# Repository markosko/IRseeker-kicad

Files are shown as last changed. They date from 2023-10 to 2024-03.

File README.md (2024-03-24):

View this project on [CADLAB.io](https://cadlab.io/project/27377).

# IRseeker-kicad

Used as replacement for IRseeker sensor and similar for Lightweight / Entry leagues with infra ball in Robocup Junior, based on STM32G431CBU6 and TSSP4038

With communication over I2C or Serial protocol.

Serial over **TX_3V** / **RX_3V** pins is **only 3.3V tolerant**!

Serial over **TX3_5V** / **RX3_5V** pins is **5V tolerant**.

**I2C** is 5V tolerant.

Logic **AND** gates **HEF4082BT** at **U2** and **U4** are optional for chip at PC6 pin input to detect if any TSSP4038 detects ball.

**AMS1117** part is not needed in case of powering from 3.3V source

Programmed by external STLINK or similar over SWD pins at J13 header.

[Basic serial code](https://github.com/markosko/IRseeker-stmduino-serial)

[Basic I2C code](https://github.com/markosko/IRseeker-stmduino-i2c)

# 3D view from KiCad

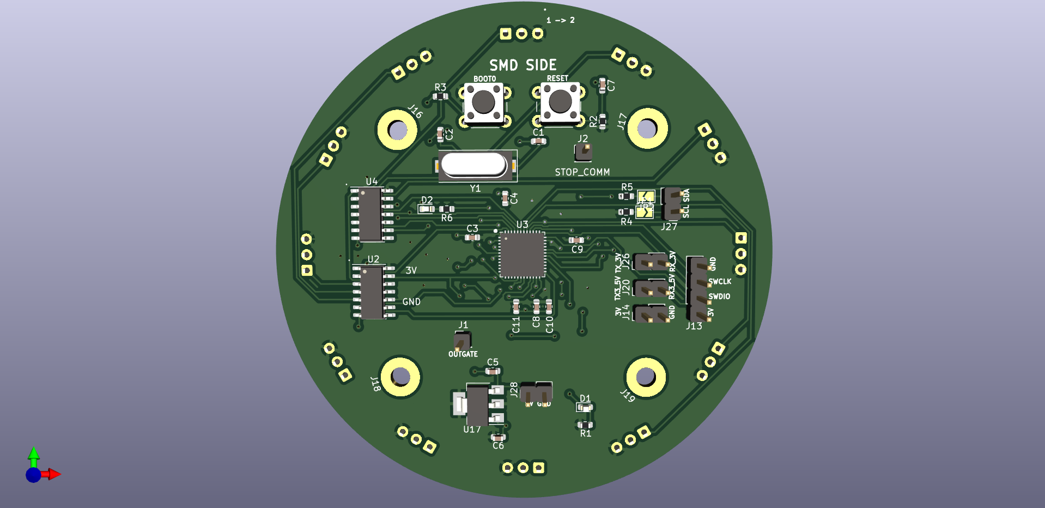
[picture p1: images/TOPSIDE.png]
Top side


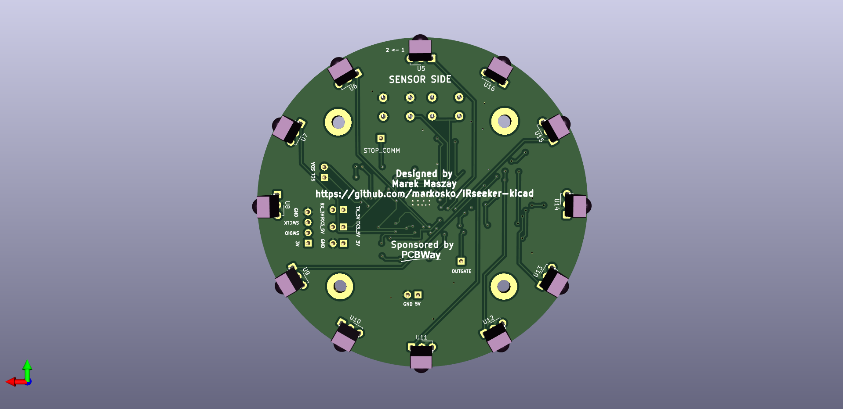
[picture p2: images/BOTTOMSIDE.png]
Bottom side


# Assembled images

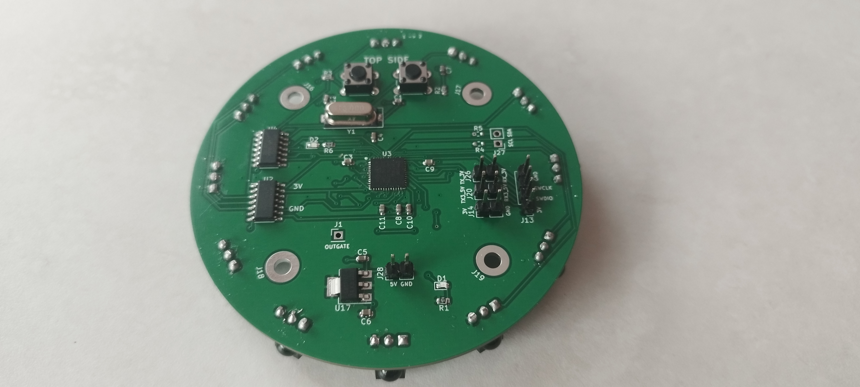
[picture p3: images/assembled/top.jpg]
Top side assembled


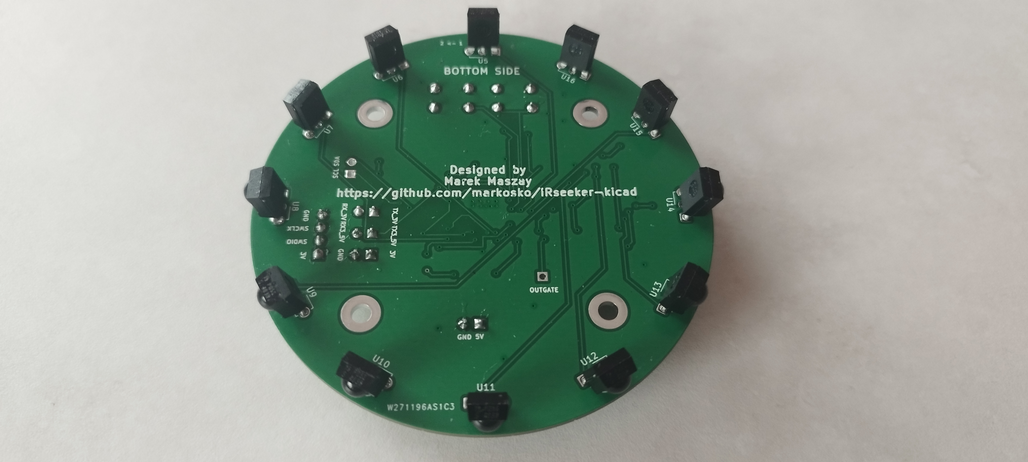
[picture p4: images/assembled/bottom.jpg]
Bottom side assembled


# Sponsored by

<p align="center">
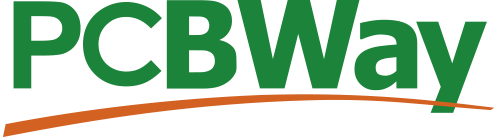
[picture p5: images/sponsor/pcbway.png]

</p>
<p align=center>
A big thanks to <a href="https://www.pcbway.com/">PCBway</a> for sponsoring my project! Their rapid-prototyping services provided top-quality PCB boards, streamlining the entire process from order to delivery. I was particularly impressed by their outstanding customer support, which was willing to change few details.
</p>

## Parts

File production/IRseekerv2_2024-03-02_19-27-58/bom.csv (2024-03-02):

Designator | Footprint | Quantity | Value | LCSC Part #
C1, C2 | 0603 | 2 | 10pF
C10 | 0603 | 1 | 4.7uF
C11, C3, C4, C7, C8, C9 | 0603 | 6 | 100nF
C5, C6 | 0603 | 2 | 10uF
D1, D2 | 0603 | 2 | LED
J1 | PinHeader_1x01_P2.54mm_Vertical | 1 | Conn_01x01_Pin
J13 | PinHeader_1x04_P2.54mm_Vertical | 1 | Conn_01x04_Pin
J14, J20, J26, J27, J28 | PinHeader_1x02_P2.54mm_Vertical | 5 | Conn_01x02_Pin
J16, J17, J18, J19 | MountingHole_3.2mm_M3_Pad | 4 | G
R1, R6 | 0603 | 2 | 330R
R2, R3 | 0603 | 2 | 10kR
R4, R5 | 0603 | 2 | 4.7kR
SW1, SW2 | SW_PUSH_6mm | 2 | SW_Push
U10, U11, U12, U13, U14, U15, U16, U5, U6, U7, U8, U9 | Vishay_MINICAST-3Pin | 12 | TSSP4038
U17 | SOT-223-3_TabPin2 | 1 | AMS1117-3.3
U2, U4 | SO-14_3.9x8.65mm_P1.27mm | 2 | HEF4082BT
U3 | QFN-48-1EP_7x7mm_P0.5mm_EP5.6x5.6mm | 1 | STM32G431CBUx
Y1 | Crystal_SMD_HC49-SD | 1 | Crystal

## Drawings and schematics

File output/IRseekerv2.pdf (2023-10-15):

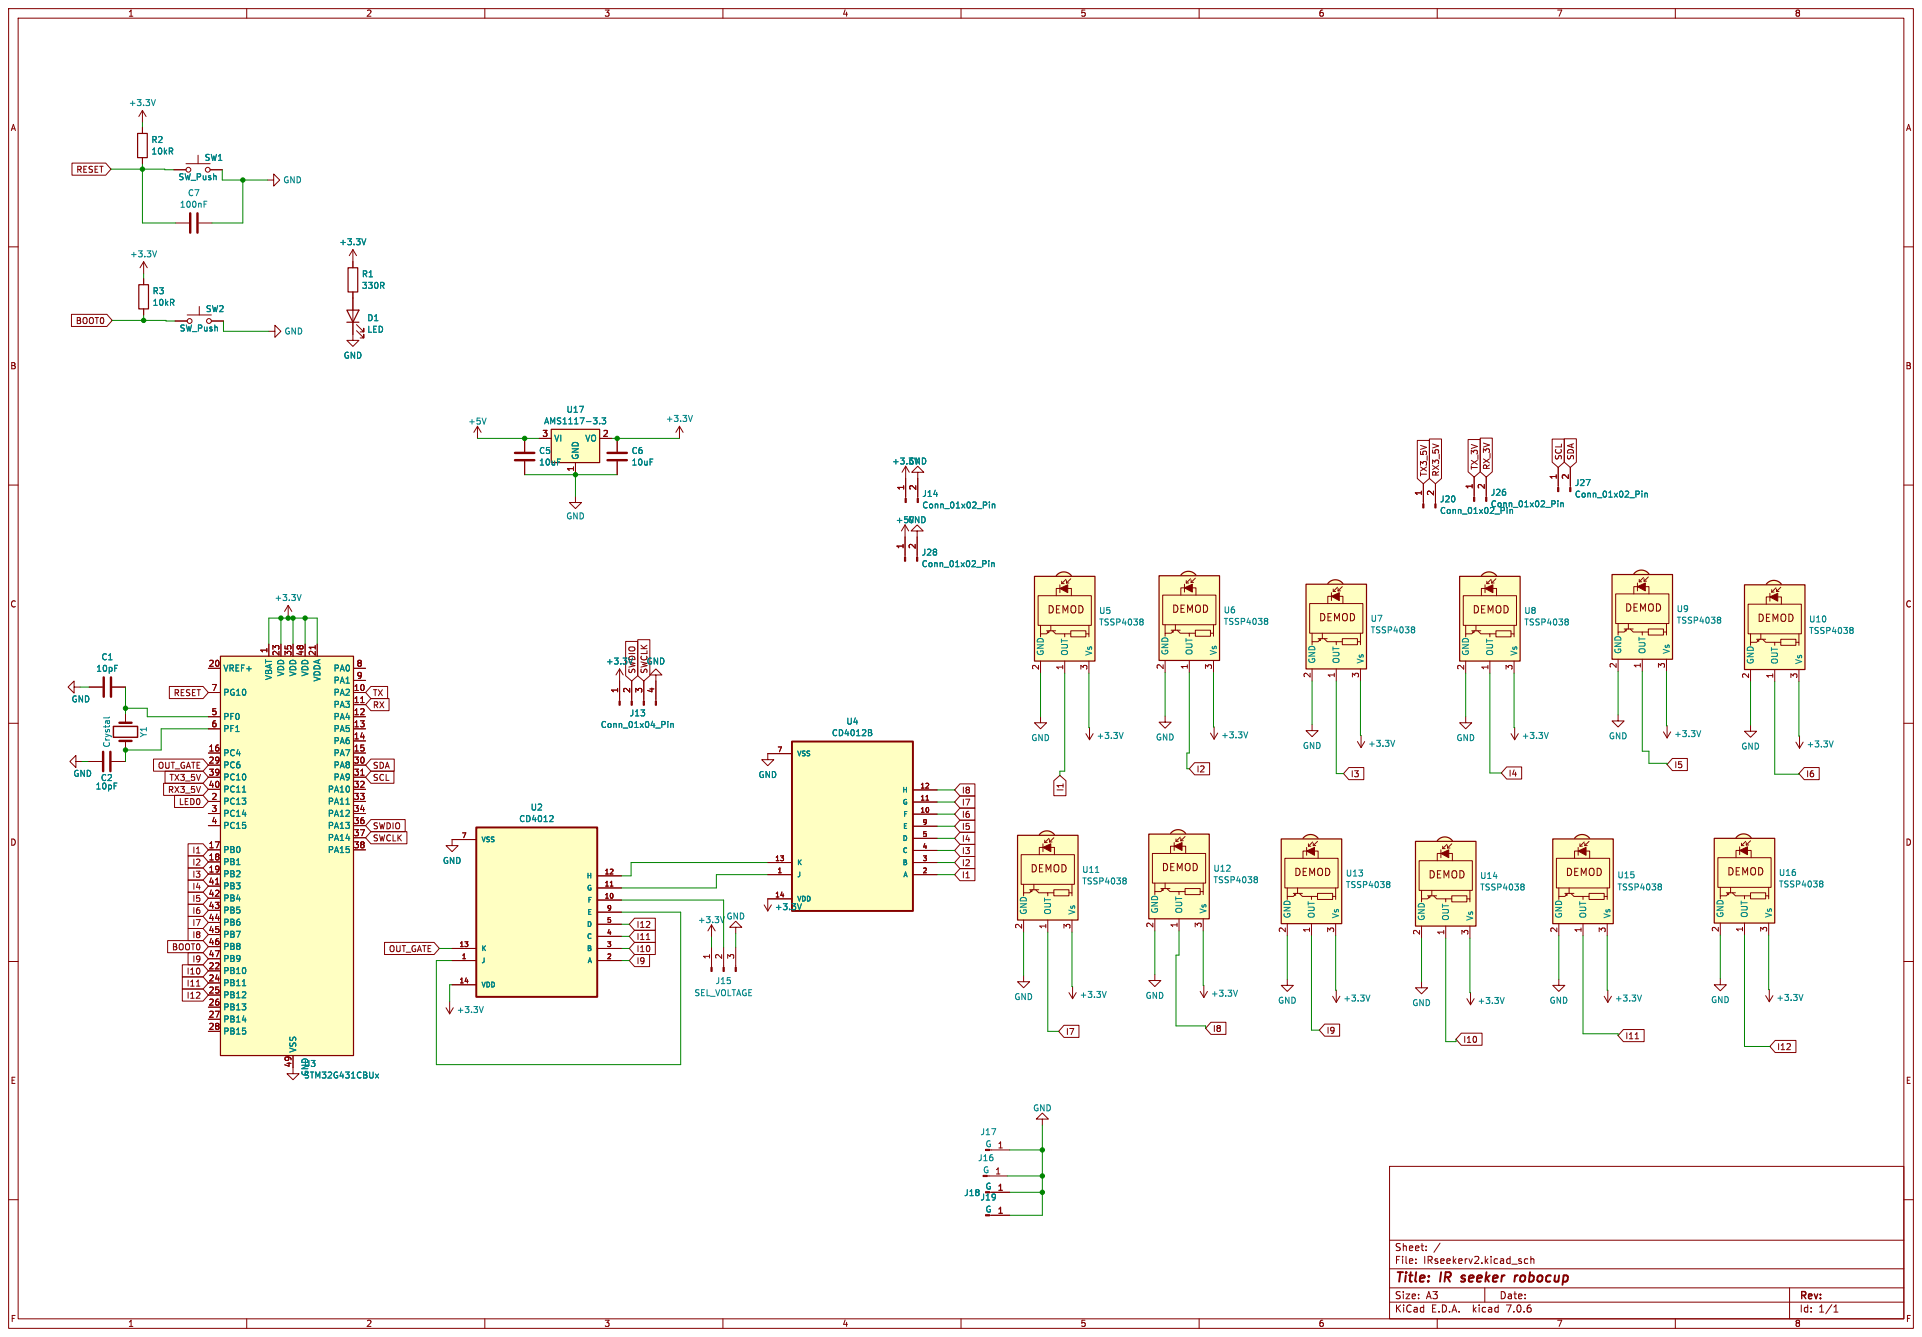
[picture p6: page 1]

1 PA2 10 PA3 11 PA4 12 PA5 13 PA6 14 PA7 15 PC4 16 PB0 17 PB1 18 PB2 19 PC13 2 VREF+ 20 VDDA 21 PB10 22 VDD 23 PB11 24 PB12 25 PB13 26 PB14 27 PB15 28 PC6 29 PC14 3 PA8 30 PA9 31 PA10 32 PA11 33 PA12 34 VDD 35 PA13 36 PA14 37 PA15 38 PC10 39 PC15 4 PC11 40 PB3 41 PB4 42 PB5 43 PB6 44 PB7 45 PB8 46 PB9 47 VDD 48 VSS 49 PF0 5 PF1 6 PG10 7 PA0 8 PA1 9 GND

2 Vs 3 U10 TSSP4038 GND GND GND +3.3V GND GND +3.3V DEMODOUT

1 PA2 10 PA3 11 PA4 12 PA5 13 PA6 14 PA7 15 PC4 16 PB0 17 PB1 18 PB2 19 PC13 2 VREF+ 20 VDDA 21 PB10 22 VDD 23 PB11 24 PB12 25 PB13 26 PB14 27 PB15 28 PC6 29 PC14 3 PA8 30 PA9 31 PA10 32 PA11 33 PA12 34 VDD 35 PA13 36 PA14 37 PA15 38 PC10 39 PC15 4 PC11 40 PB3 41 PB4 42 PB5 43 PB6 44 PB7 45 PB8 46 PB9 47 VDD 48 VSS 49 PF0 5 PF1 6 PG10 7 PA0 8 PA1 9 U3STM32G431CBUx

Id: 1/1 Title: IR seeker robocup

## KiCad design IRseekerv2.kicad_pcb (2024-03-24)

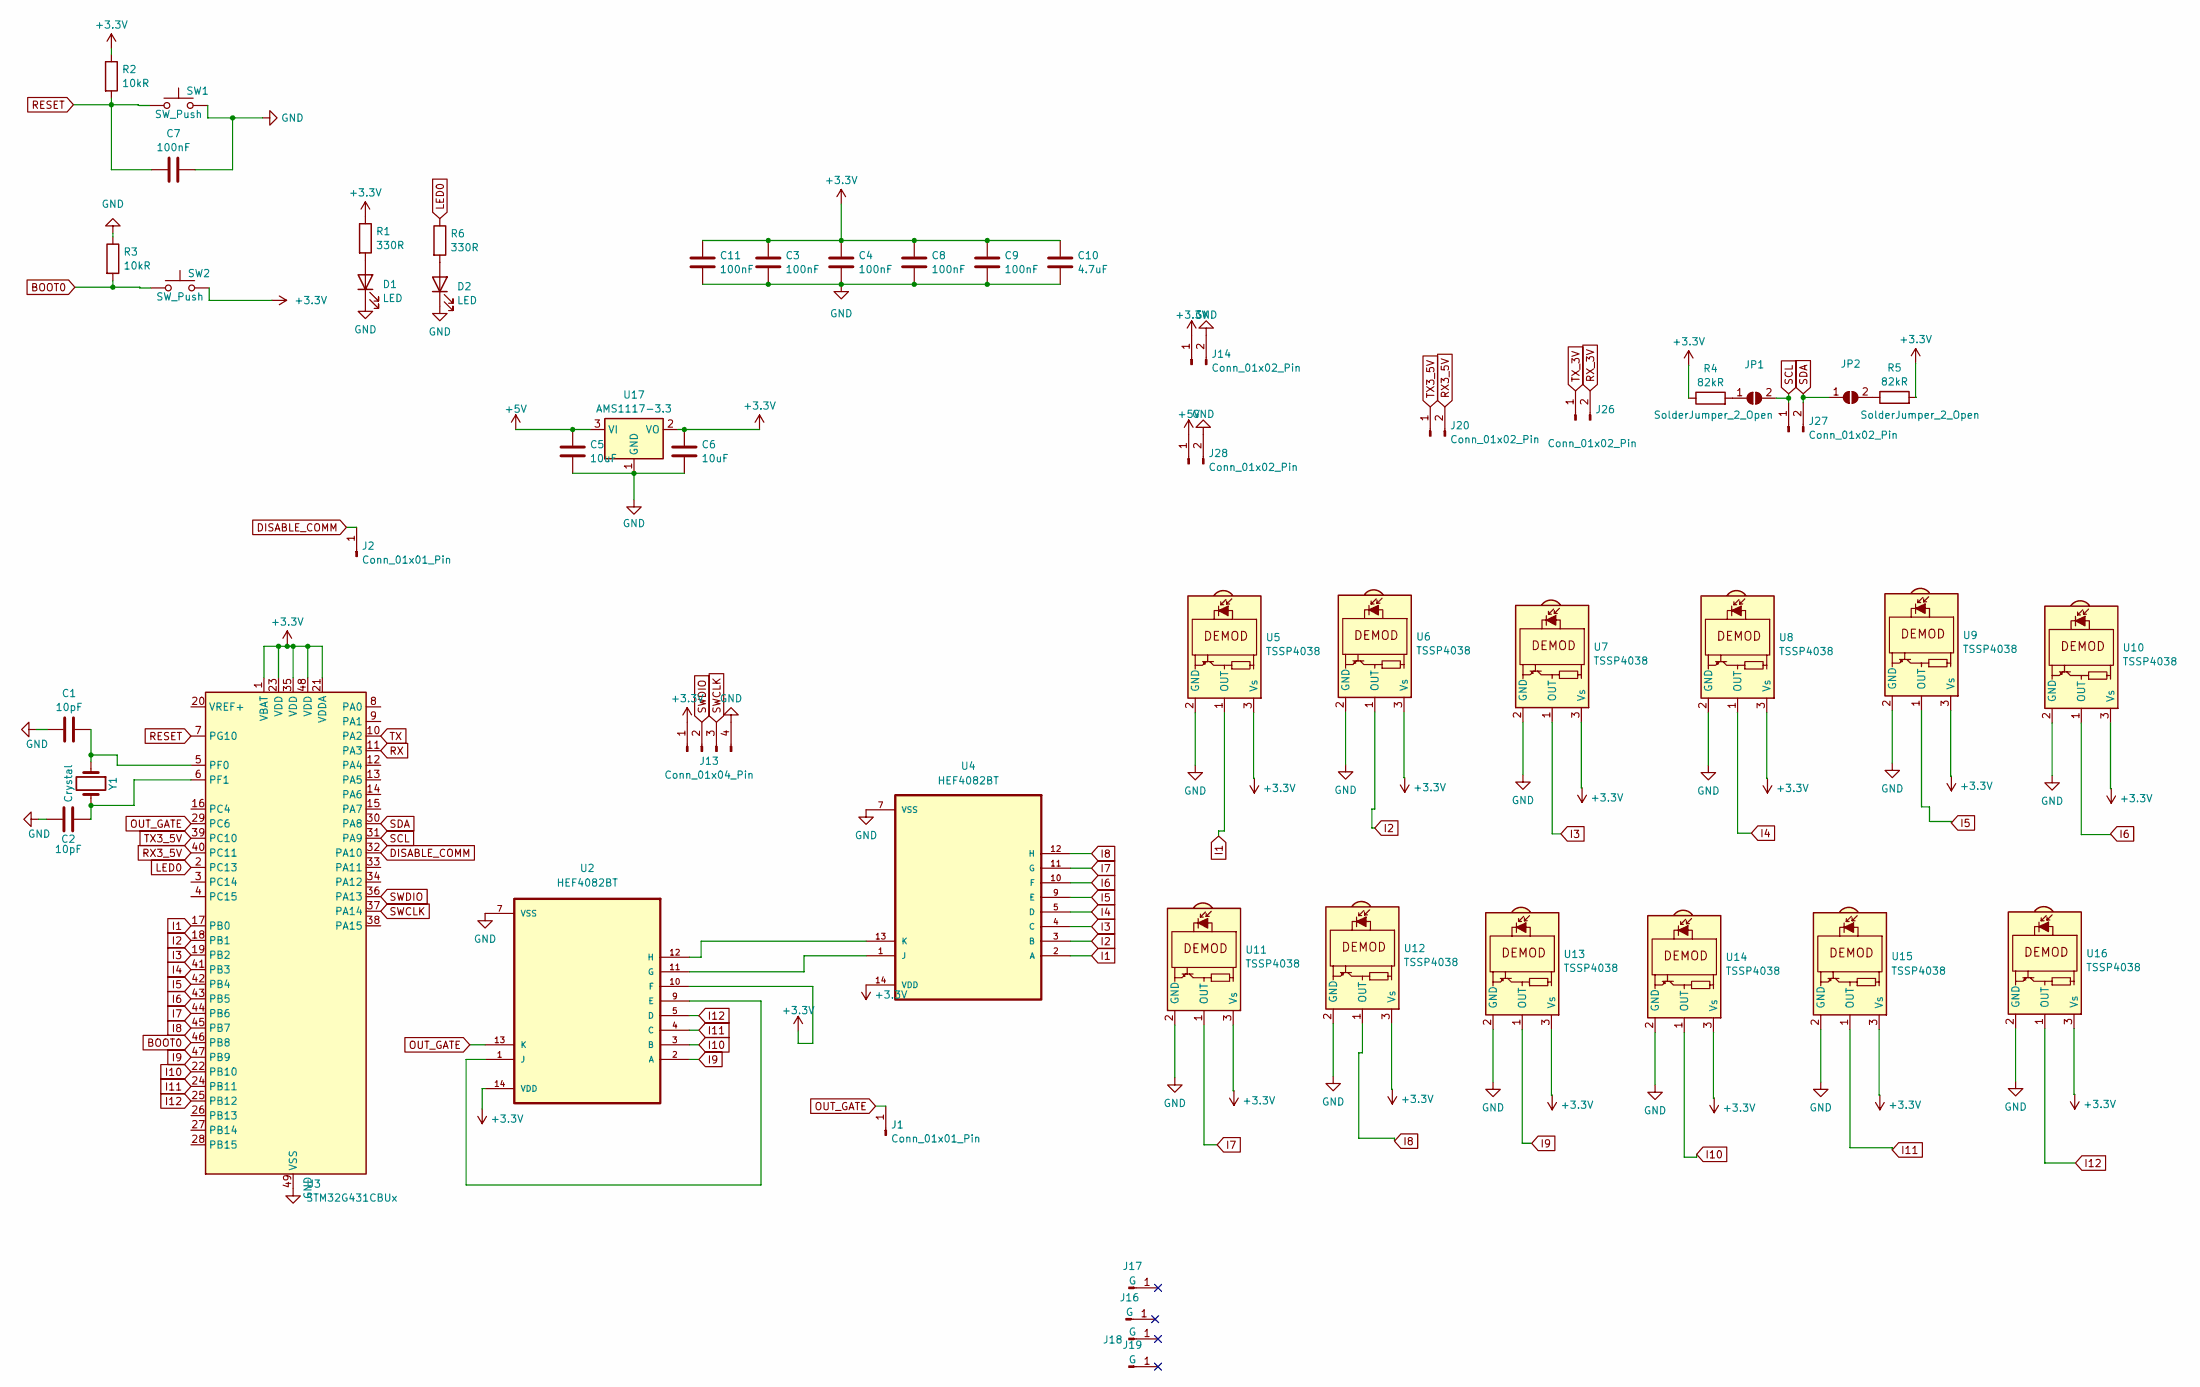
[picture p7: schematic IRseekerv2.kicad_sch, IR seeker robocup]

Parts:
C1, C2: 10pF; C_0603_1608Metric
C3, C4, C7, C8, C9, C11: 100nF; C_0603_1608Metric
C5, C6: 10uF; C_0603_1608Metric
C10: 4.7uF; C_0603_1608Metric
D1, D2: LED; LED_0603_1608Metric
J1, J2: Conn_01x01_Pin; PinHeader_1x01_P2.54mm_Vertical
J13: Conn_01x04_Pin; PinHeader_1x04_P2.54mm_Vertical
J14, J20, J26, J27, J28: Conn_01x02_Pin; PinHeader_1x02_P2.54mm_Vertical
J16, J17, J18, J19: G; MountingHole_3.2mm_M3_Pad
JP1, JP2: SolderJumper_2_Open; SolderJumper-2_P1.3mm_Open_TrianglePad1.0x1.5mm
R1, R6: 330R; R_0603_1608Metric
R2, R3: 10kR; R_0603_1608Metric
R4, R5: 82kR; R_0603_1608Metric
SW1, SW2: SW_Push; SW_PUSH_6mm
U2, U4: HEF4082BT; SO-14_3.9x8.65mm_P1.27mm
U3: STM32G431CBUx; QFN-48-1EP_7x7mm_P0.5mm_EP5.6x5.6mm
U5, U6, U7, U8, U9, U10, U11, U12, U13, U14, U15, U16: TSSP4038; Vishay_MINICAST-3Pin
U17: AMS1117-3.3; SOT-223-3_TabPin2
Y1: Crystal; Crystal_SMD_HC49-SD

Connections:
+3.3V: C3.2, C4.2, C6.2, C8.2, C9.2, C10.2, C11.2, J13.1, J14.1, R1.1, R2.1, R4.1, R5.2, SW2.2, U2.10 (F), U2.14 (VDD), U3.1 (VBAT), U3.21 (VDDA), U3.23 (VDD), U3.35 (VDD), U3.48 (VDD), U4.14 (VDD), U5.3 (Vs), U6.3 (Vs), U7.3 (Vs), U8.3 (Vs), U9.3 (Vs), U10.3 (Vs), U11.3 (Vs), U12.3 (Vs), U13.3 (Vs), U14.3 (Vs), U15.3 (Vs), U16.3 (Vs), U17.2 (VO)
+5V: C5.2, J28.1, U17.3 (VI)
BOOT0: R3.2, SW2.1, U3.46 (PB8)
DISABLE_COMM: J2.1, U3.32 (PA10)
GND: C1.1, C2.1, C3.1, C4.1, C5.1, C6.1, C7.1, C8.1, C9.1, C10.1, C11.1, D1.1 (K), D2.1 (K), J13.4, J14.2, J28.2, R3.1, SW1.2, U2.7 (VSS), U3.49 (VSS), U4.7 (VSS), U5.2 (GND), U6.2 (GND), U7.2 (GND), U8.2 (GND), U9.2 (GND), U10.2 (GND), U11.2 (GND), U12.2 (GND), U13.2 (GND), U14.2 (GND), U15.2 (GND), U16.2 (GND), U17.1 (GND)
I1: U3.17 (PB0), U4.2 (A), U5.1 (OUT)
I2: U3.18 (PB1), U4.3 (B), U6.1 (OUT)
I3: U3.19 (PB2), U4.4 (C), U7.1 (OUT)
I4: U3.41 (PB3), U4.5 (D), U8.1 (OUT)
I5: U3.42 (PB4), U4.9 (E), U9.1 (OUT)
I6: U3.43 (PB5), U4.10 (F), U10.1 (OUT)
I7: U3.44 (PB6), U4.11 (G), U11.1 (OUT)
I8: U3.45 (PB7), U4.12 (H), U12.1 (OUT)
I9: U2.2 (A), U3.47 (PB9), U13.1 (OUT)
I10: U2.3 (B), U3.22 (PB10), U14.1 (OUT)
I11: U2.4 (C), U3.24 (PB11), U15.1 (OUT)
I12: U2.5 (D), U3.25 (PB12), U16.1 (OUT)
LED0: R6.1, U3.2 (PC13)
unnamed: D1.2 (A), R1.2
unnamed: D2.2 (A), R6.2
unnamed: JP1.1 (A), R4.2
unnamed: JP2.2 (B), R5.1
unnamed: U2.1 (J), U2.9 (E)
unnamed: U2.11 (G), U4.1 (J)
unnamed: U2.12 (H), U4.13 (K)
unnamed: C1.2, U3.5 (PF0), Y1.1
unnamed: C2.2, U3.6 (PF1), Y1.2
OUT_GATE: J1.1, U2.13 (K), U3.29 (PC6)
RESET: C7.2, R2.2, SW1.1, U3.7 (PG10)
RX: U3.11 (PA3)
RX3_5V: J20.2, U3.40 (PC11)
RX_3V: J26.2
SCL: J27.1, JP1.2 (B), U3.31 (PA9)
SDA: J27.2, JP2.1 (A), U3.30 (PA8)
SWCLK: J13.3, U3.37 (PA14)
SWDIO: J13.2, U3.36 (PA13)
TX: U3.10 (PA2)
TX3_5V: J20.1, U3.39 (PC10)
TX_3V: J26.1

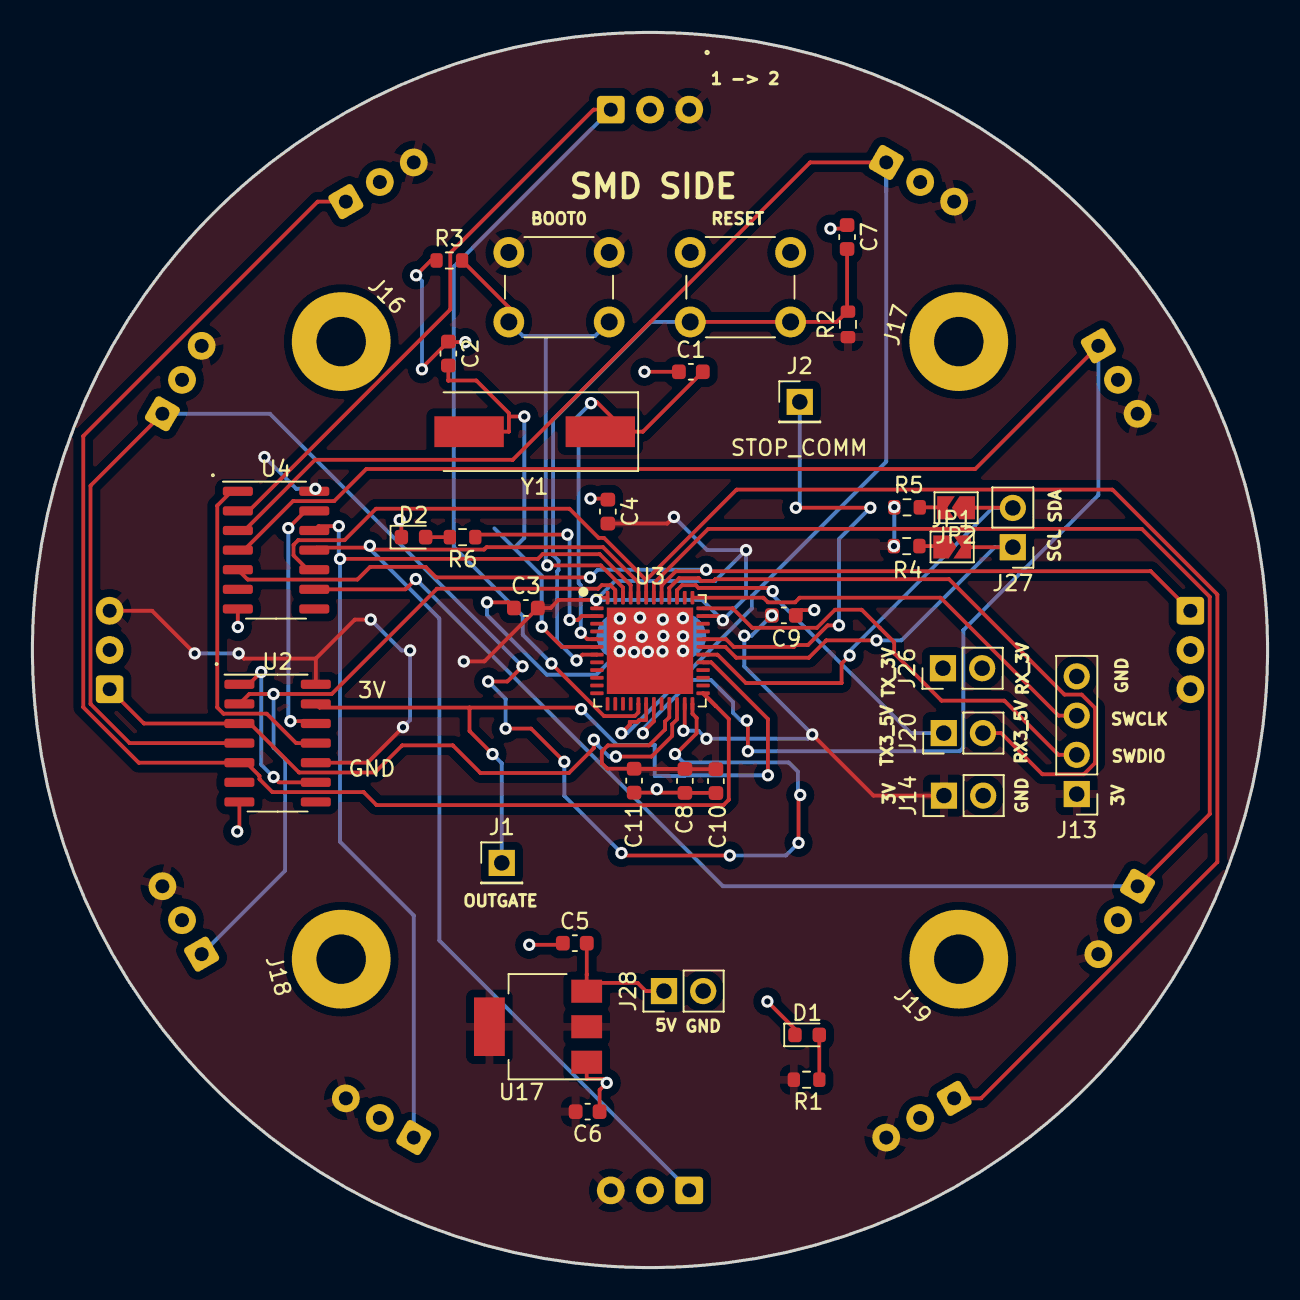
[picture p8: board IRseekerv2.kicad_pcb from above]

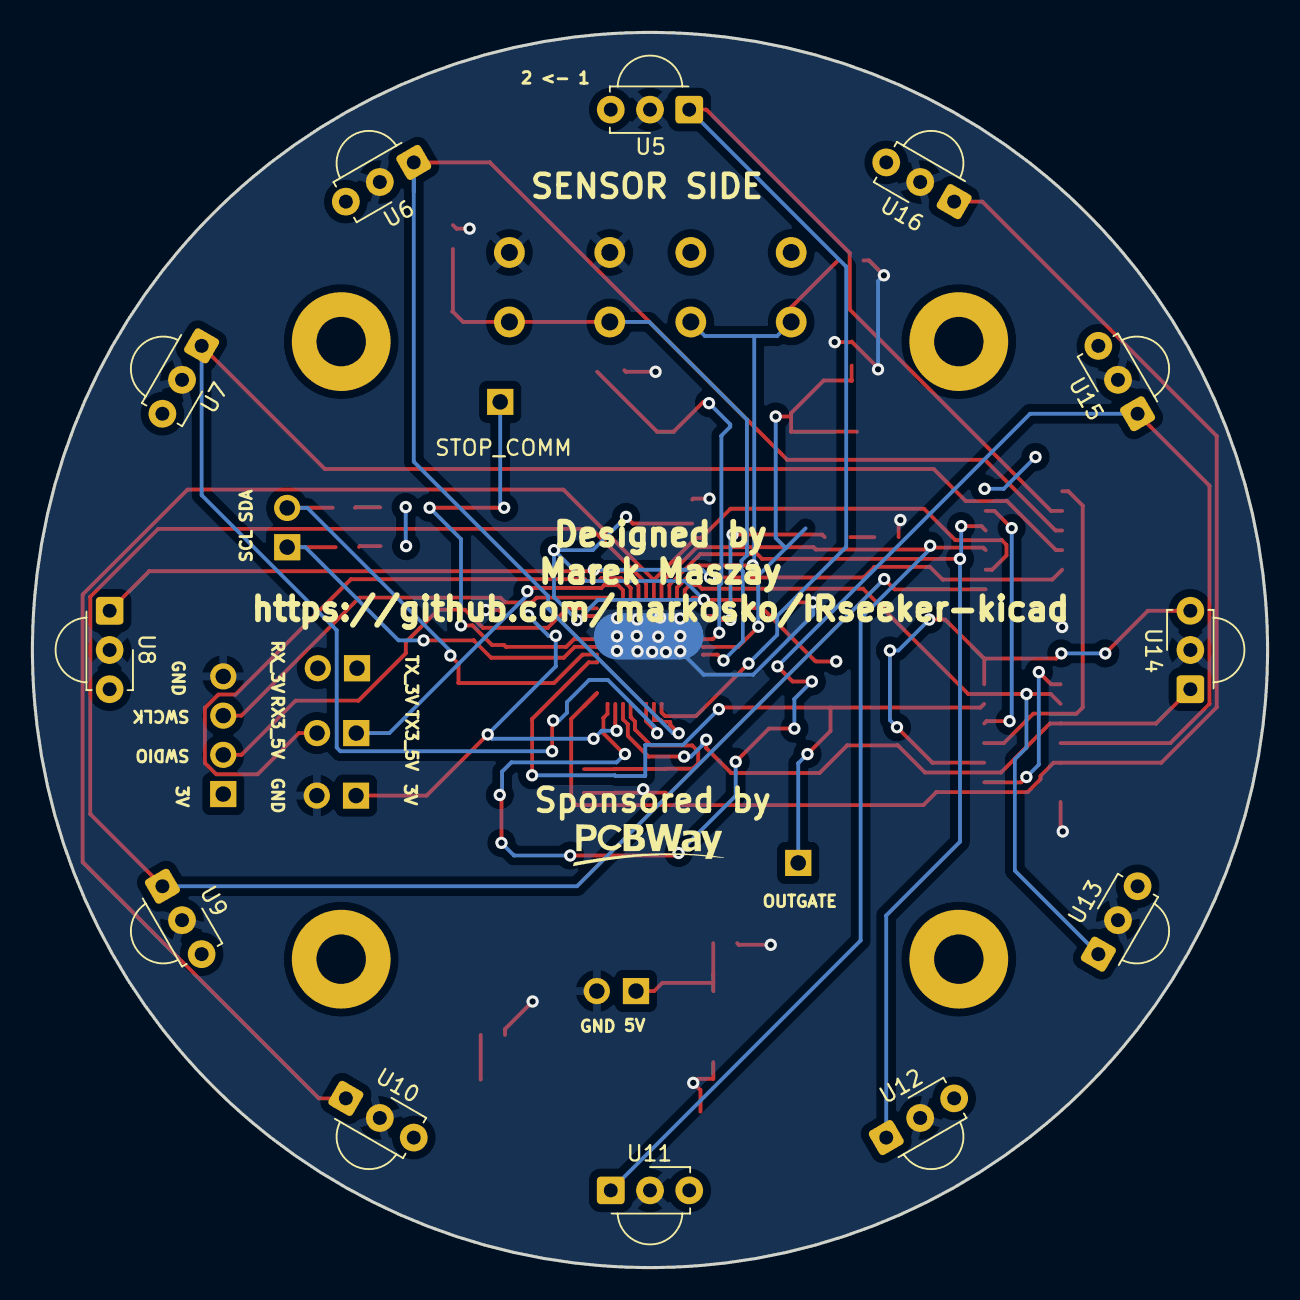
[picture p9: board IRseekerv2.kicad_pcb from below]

Board: 2 copper layers, 80.0 x 80.0 mm, 52 parts (12 on the bottom side), 35 nets.

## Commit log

2023-10-15 reworked to put STM32G431CBU6 on board
    [1616 RGB LED Anode.fcstd, 1616 RGB LED Assembly.fcstd, 1616 RGB LED Blue.fcstd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]
2023-10-15 Writen more info in README and removed output jumper in PCB
    [IRseekerv2.kicad_pcb, bom.csv, designators.csv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]
2023-10-19 I2C pullup resistors
    [IRseekerv2.kicad_pcb, IRseekerv2.kicad_sch, freerouting.dsn]
2023-10-19 Disconnected mounting holes from ground, reroute some connections because of I2C pullups
    [IRseekerv2.kicad_pcb, IRseekerv2.kicad_sch]
2023-10-19 Added label to bottom side
    [IRseekerv2.kicad_pcb]
2023-11-11 Add forgotten decoupling capacitors and change footprints
    [IRseekerv2.kicad_sch]
2023-11-12 Reworked to some smd components
    [IRseekerv2.kicad_pcb, IRseekerv2.kicad_sch, bom.csv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]
2023-12-25 update production and images to last version
    [bom.csv, designators.csv, positions.csv]
2023-12-29 BOOT0 pulldown instead of pullup
    [IRseekerv2.kicad_pcb, IRseekerv2.kicad_sch, bom.csv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]
2023-12-30 Added label for site and "designed by"
    [IRseekerv2.kicad_pcb, bom.csv, designators.csv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]
2024-02-11 removed SEL_VOlTAGE and added OUTGATE pin out
    [IRseekerv2.kicad_pcb, IRseekerv2.kicad_sch, bom.csv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]
2024-03-02 change crystal to smd version
    [IRseekerv2.kicad_pcb, IRseekerv2.kicad_sch, bom.csv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]
2024-03-05 link to I2C example repo code
2024-03-24 STOP_COMM pin, solder pads for resistors on I2C lines
    [IRseekerv2.kicad_pcb, IRseekerv2.kicad_sch]
